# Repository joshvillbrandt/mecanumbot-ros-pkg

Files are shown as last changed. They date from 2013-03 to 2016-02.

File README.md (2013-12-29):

mecanumbot-ros-pkg
==================

A ROS package for the Mecanumbot robot.

## Summary

The Mecanumbot robot is a robotic development platform designed, built, and maintained by [Josh Villbrandt](mailto:josh@javconcepts.com). It features a holonomic drive platform with mecanum wheels as well as a 2D laser scanner and an RGB-D camera. Research goals in localization, navigation, and object recognition from point clouds. Learn more about the Mecanumbot at [JAV Concepts](http://javconcepts.com/tag/mecanumbot/).

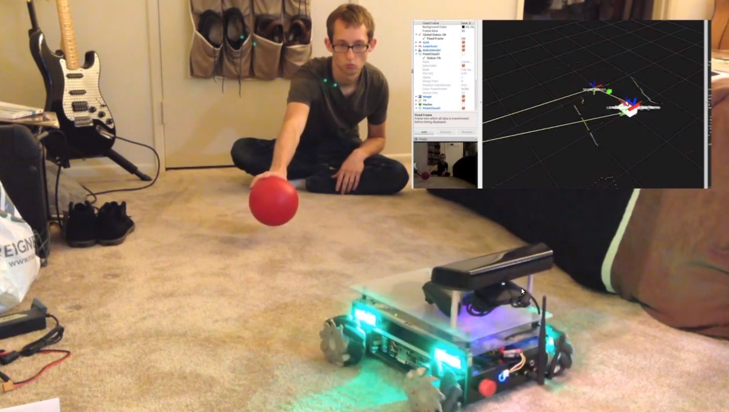
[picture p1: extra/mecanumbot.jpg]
Mecanumbot


## Documentation

A variety of guides are available in the `docs/` folder.

* [Setup Guide](docs/Setup Guide.md)
* [Usage Guide](docs/Usage Guide.md)
* [Implementation Guide](docs/Implementation Guide.md)
* [Work Log](docs/Work Log.md)
* [Todo List](docs/Todo List.md)

## Releases

This package uses [semantic versioning](http://semver.org/).

| Version | Notes |
| --- | --- |
| future | Re-added gmapping launch file. |
| future | Target follower now uses dynamic_reconfigure. Fixed phantom LED and motor message. |
| future | Refactoring LED messages and xbox controller mapping for LEDs. Added barometer telemetry. Refactored documentation.  |
| [v0.3.0](https://github.com/joshvillbrandt/mecanumbot/releases/tag/v0.3.0) | Ball tracking code refactored to HSV. Added power board telemetry. |
| [v0.2.0](https://github.com/joshvillbrandt/mecanumbot/releases/tag/v0.2.0) | Updating for Hydro. New ball tracking with target follower. |
| [v0.1.0](https://github.com/joshvillbrandt/mecanumbot/releases/tag/v0.1.0) | Last working version of the mecanumbot package for ROS Groovy. |

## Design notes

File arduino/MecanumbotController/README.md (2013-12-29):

mecanumbot-controller
=====================

An Arduino sketch for the mecanumbot low-level control node.

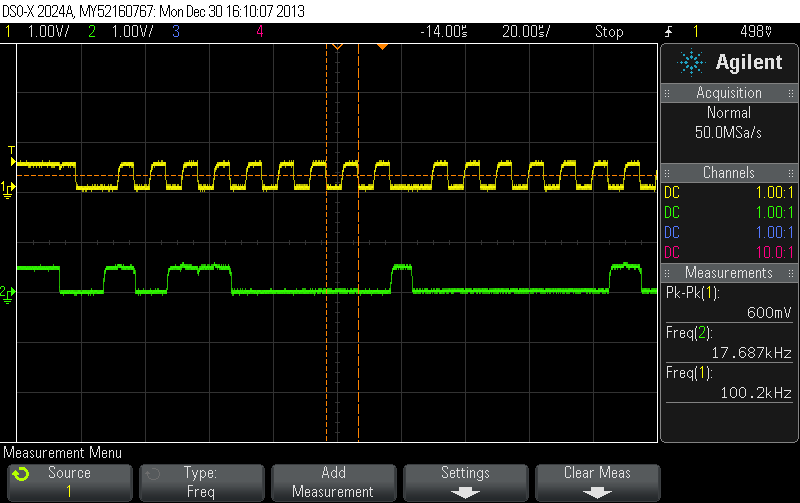
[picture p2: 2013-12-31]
extra/i2c_2.8k.png

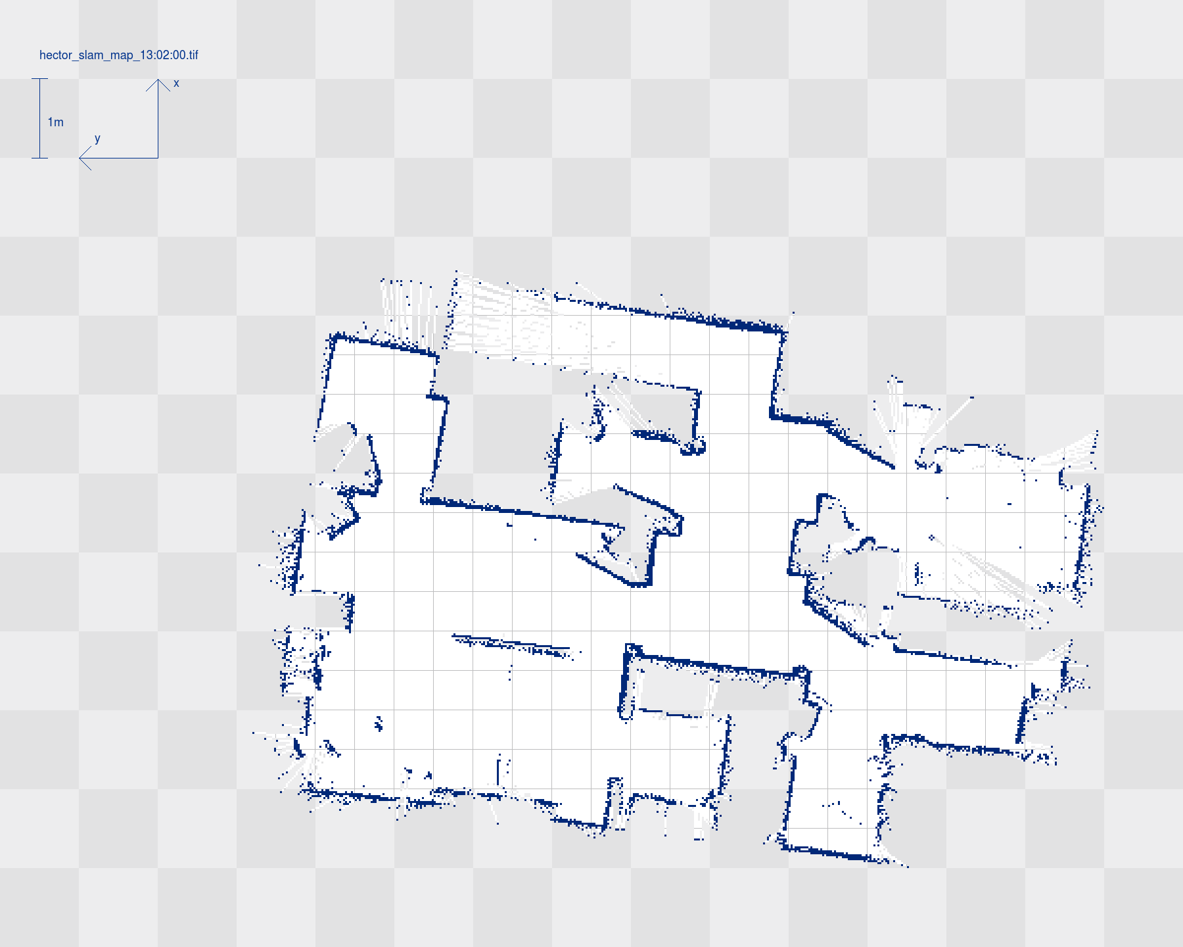
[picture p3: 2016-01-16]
maps/hector_slam_map_apartment_upstairs.tif

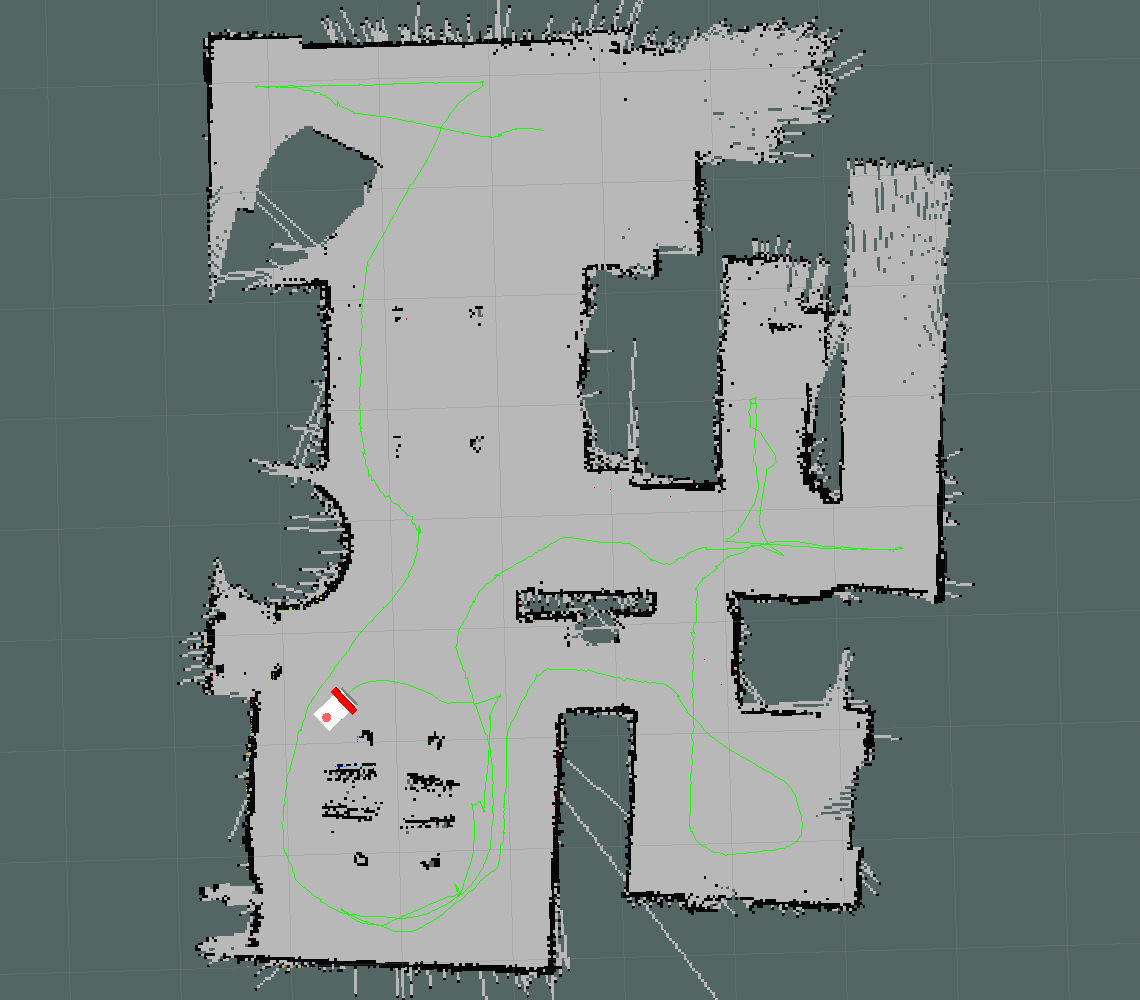
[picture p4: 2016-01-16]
maps/hector_slam_map_apartment_downstairs.jpg

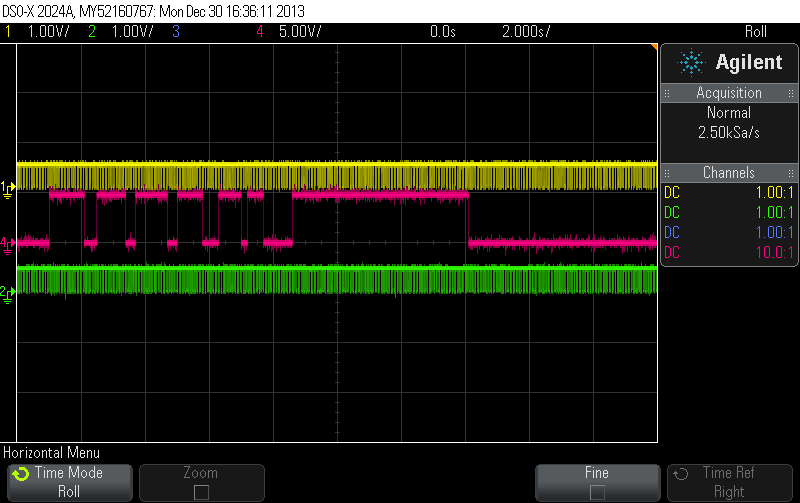
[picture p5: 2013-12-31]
extra/i2c_outpin.png

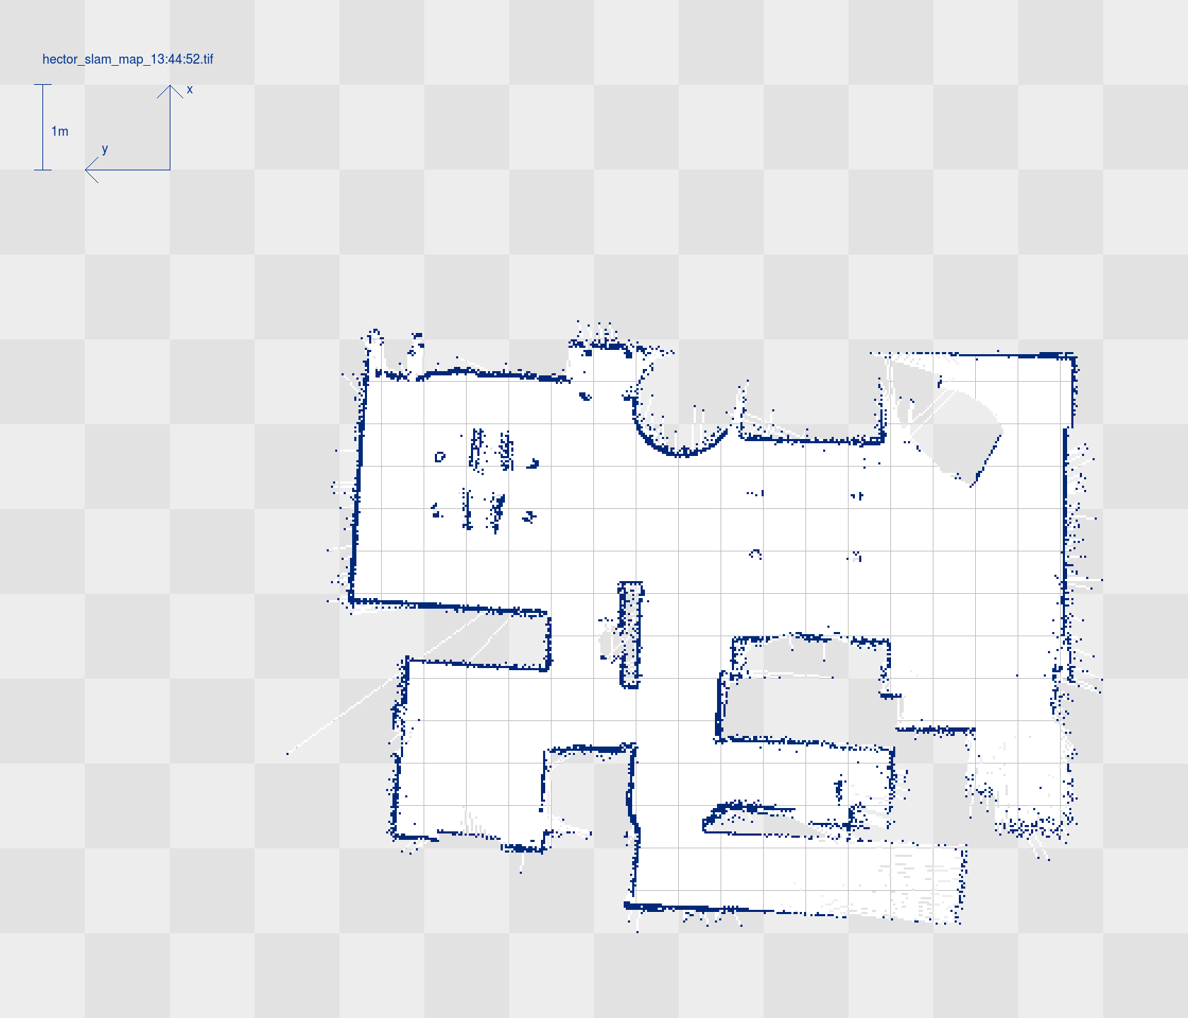
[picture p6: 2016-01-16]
maps/hector_slam_map_apartment_downstairs.tif

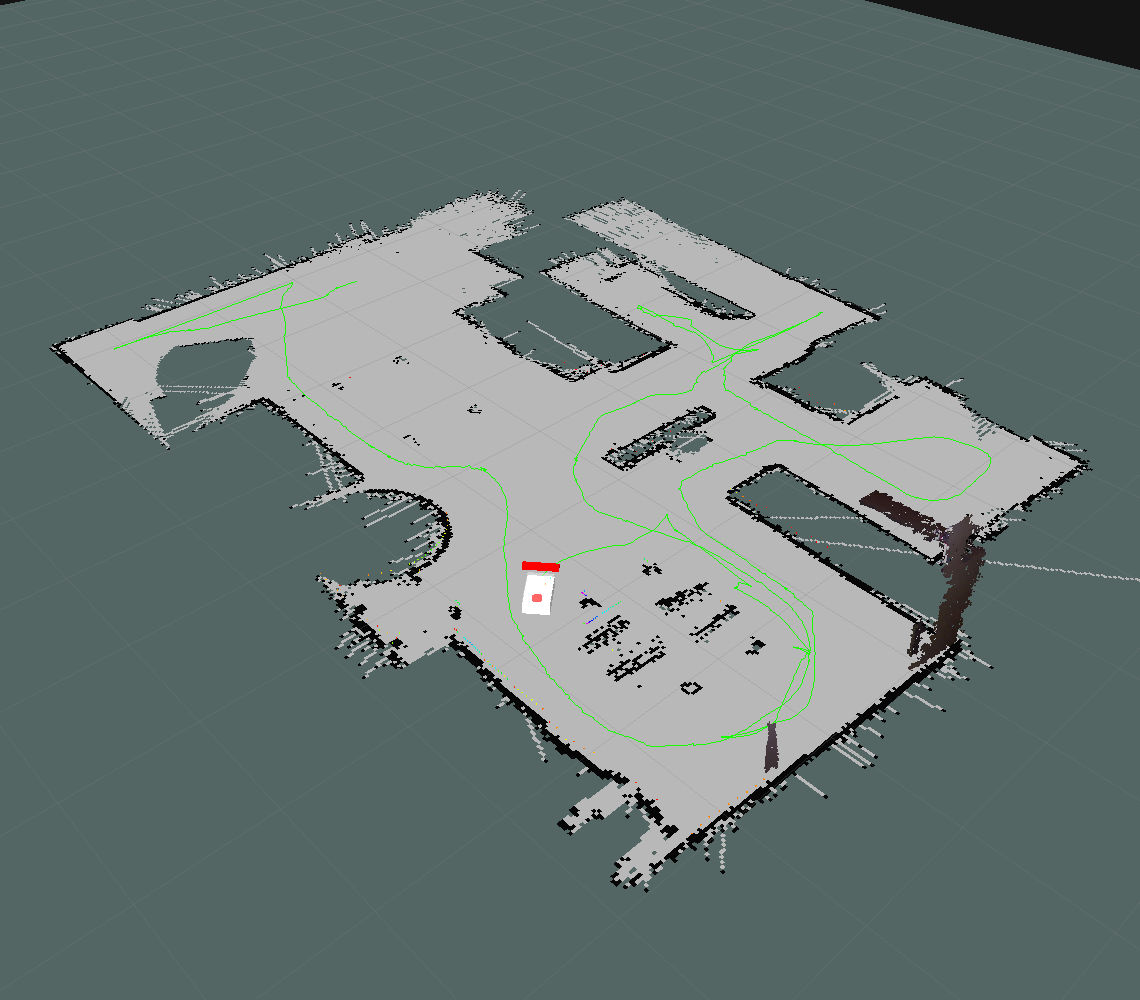
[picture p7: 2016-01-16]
maps/hector_slam_map_apartment_downstairs_iso.jpg

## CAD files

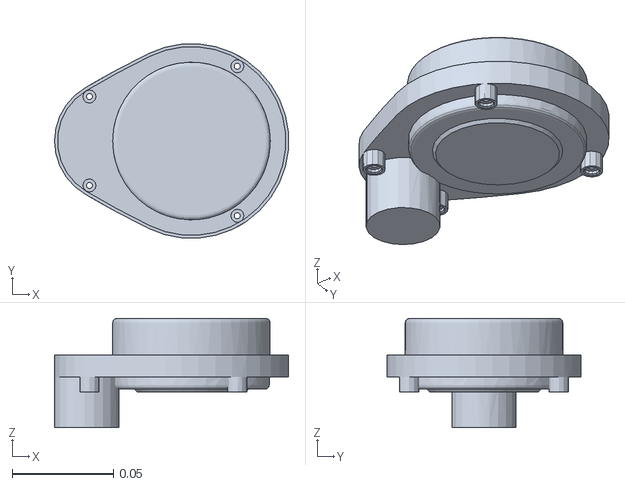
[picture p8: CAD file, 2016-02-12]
description/base_laser.STL
0.116 x 0.0961 x 0.054

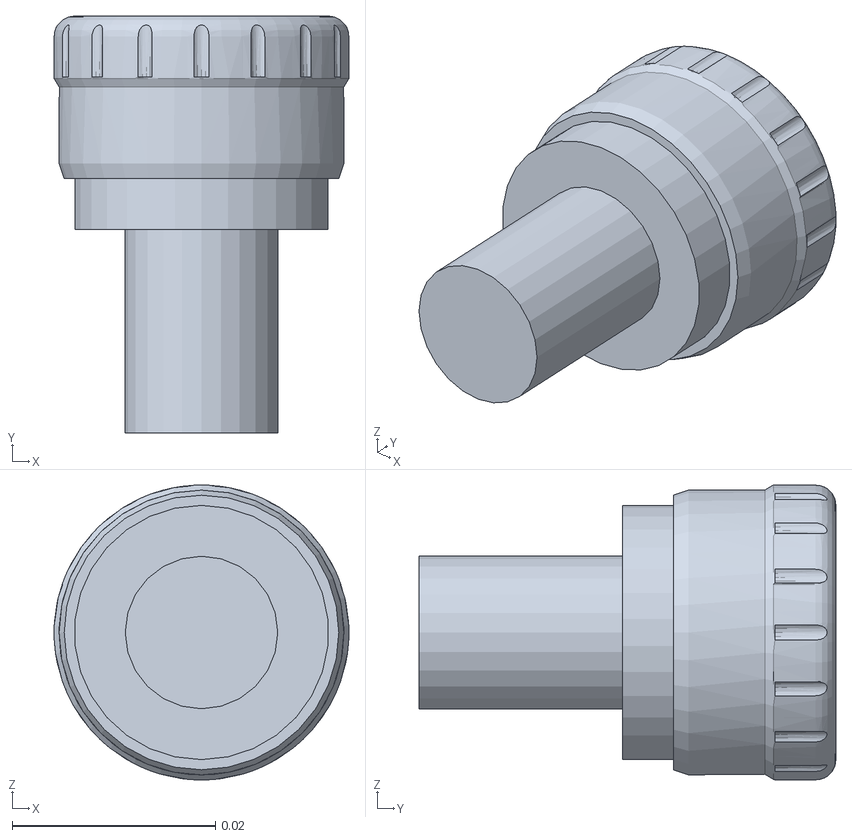
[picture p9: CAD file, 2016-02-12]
description/e_stop.STL
0.029 x 0.041 x 0.029

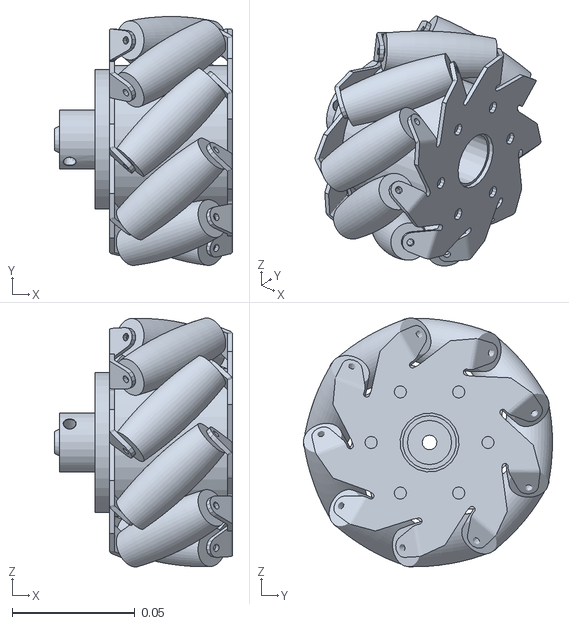
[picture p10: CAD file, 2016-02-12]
description/fr_wheel_link.STL
0.0724 x 0.101 x 0.101

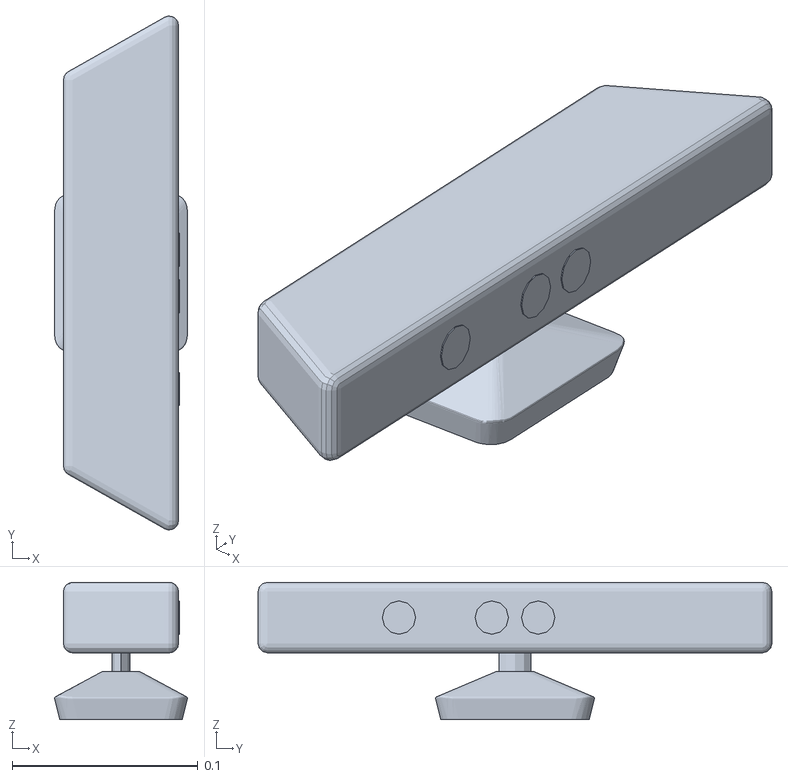
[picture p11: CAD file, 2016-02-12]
description/camera_link.STL
0.0716 x 0.277 x 0.074

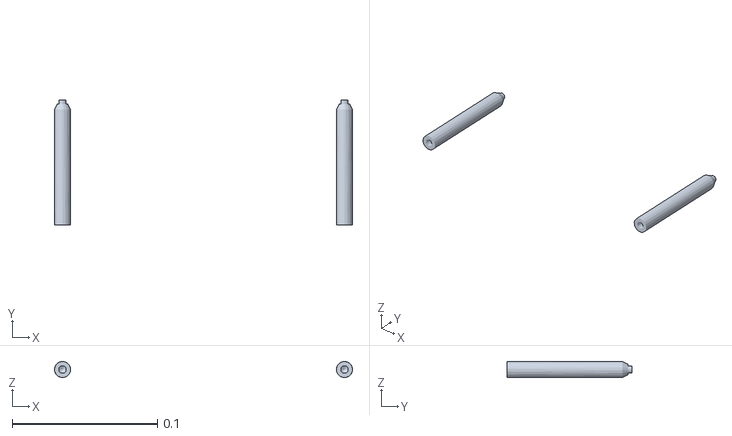
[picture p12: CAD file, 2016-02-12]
description/camera_supports.STL
0.205 x 0.0859 x 0.0111

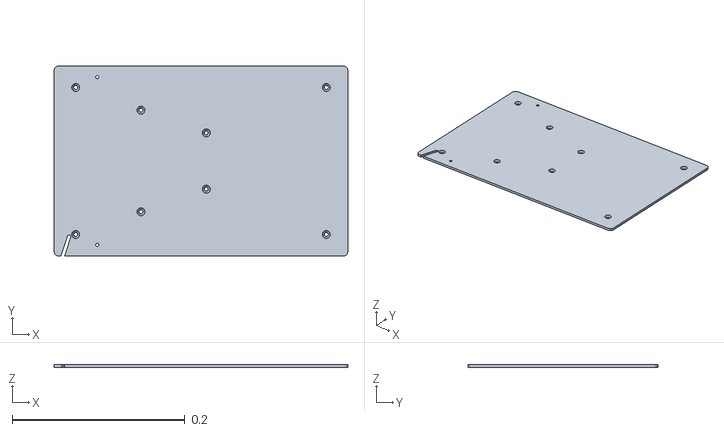
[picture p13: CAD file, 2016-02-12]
description/top_plate_link.STL
0.34 x 0.22 x 0.00317

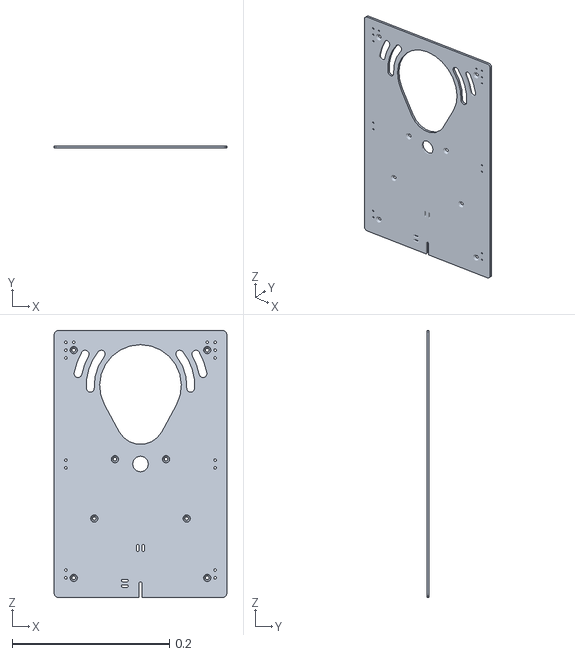
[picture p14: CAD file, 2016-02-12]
description/mid_plate_link.STL
0.22 x 0.00317 x 0.34

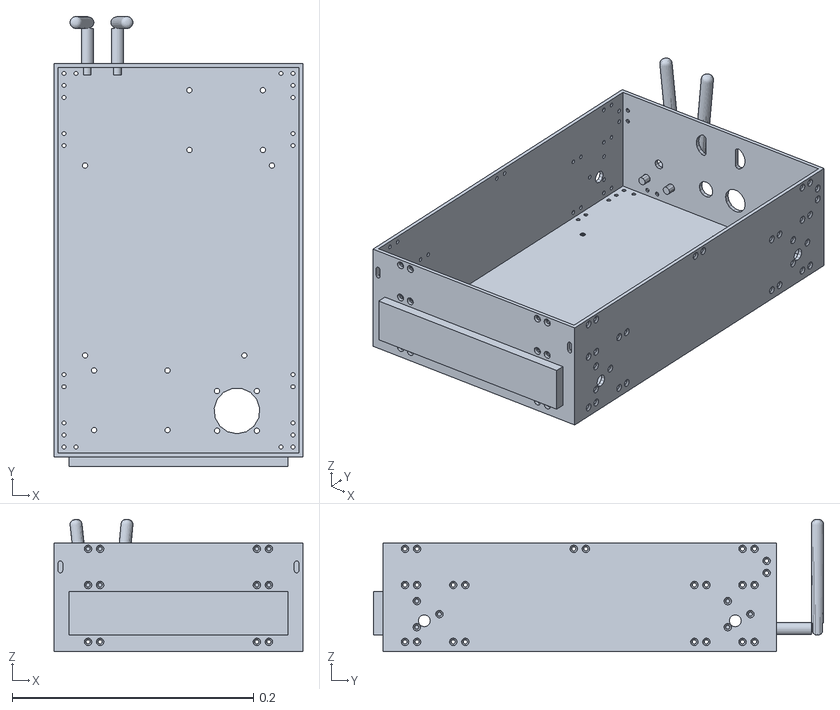
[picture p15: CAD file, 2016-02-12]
description/base_link.STL
0.206 x 0.373 x 0.11

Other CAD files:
description/bl_wheel_link.STL
description/br_wheel_link.STL
description/fl_wheel_link.STL

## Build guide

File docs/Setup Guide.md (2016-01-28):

# Mecanumbot Setup Guide

Complete the following steps to install the mecanumbot package on a new robot. If you are not familiar with ROS, please complete the [ROS Tutorials](http://wiki.ros.org/ROS/Tutorials) before continuing.

## Install Ubuntu 14.04

Use your favorite method to install a fresh copy of Ubuntu Trusty. Pay special attention to the hostname you choose during installation - this will be the hostname of your robot.

After installtion completes, install these additional, required packages:

```bash
sudo apt-get update
sudo apt-get install -y git openssh-server screen
```

## Optional Environment Setup

The following packages are optional and are intended for a development workstation:

```bash
# old gnome (don't forget to enable "Static Application Switcher" for alt-tab)
sudo apt-get install -y gnome-session-fallback compiz compiz-plugins-extra compizconfig-settings-manager

# sublime 3
sudo add-apt-repository ppa:webupd8team/sublime-text-3
sudo apt-get update
sudo apt-get install -y sublime-text-installer

# zsh
sudo apt-get install -y zsh
chsh -s $(which zsh)
sh -c "$(wget https://raw.github.com/robbyrussell/oh-my-zsh/master/tools/install.sh -O -)"

# scm_breeze
git clone git://github.com/ndbroadbent/scm_breeze.git ~/.scm_breeze
~/.scm_breeze/install.sh
source ~/.zshrc
```

## Install ROS

If you have earlier versions of ROS installed, it might be best to uninstall them first. If you have problems with the subsequent install statements, try using aptitude instead of apt-get to resolve dependencies.

```
sudo apt-get purge ros-indigo-*
```

Follow the [ROS Jade Install Guide](http://wiki.ros.org/jade/Installation/Ubuntu) to get ROS up an running. This boils down to:

```bash
sudo sh -c 'echo "deb http://packages.ros.org/ros/ubuntu $(lsb_release -sc) main" > /etc/apt/sources.list.d/ros-latest.list'
sudo apt-key adv --keyserver hkp://pool.sks-keyservers.net:80 --recv-key 0xB01FA116
sudo apt-get update
sudo apt-get install -y ros-jade-desktop-full
sudo rosdep init
rosdep update
```

In addition to the standard desktop package, you'll want to install a few other packages that the mecanumbot package depends on. The first few lines of this are from the [PCL Ubuntu install page](http://pointclouds.org/downloads/linux.html).

```bash
sudo add-apt-repository ppa:v-launchpad-jochen-sprickerhof-de/pcl
sudo apt-get update
sudo apt-get install -y libpcl-all ros-jade-pcl-ros ros-jade-joy ros-jade-openni-camera ros-jade-openni-launch ros-jade-rosserial-arduino ros-jade-rosserial ros-jade-robot-upstart ros-jade-rqt-robot-plugins ros-jade-hector-slam
```

To complete the install, source the ROS bash file. You'll probably want to stick this in your `~/.zshrc` file as well.

```bash
# for bash
echo "source /opt/ros/jade/setup.bash" >> ~/.bashrc
source ~/.bashrc

# for zsh
echo "source /opt/ros/jade/setup.zsh" >> ~/.zshrc
source ~/.zshrc
```

## Create a Workspace

Create a Catkin workspace by following the [create a workspace](http://wiki.ros.org/catkin/Tutorials/create_a_workspace) guide on ros.org. This boils down to:

```bash
mkdir -p ~/catkin_ws/src
cd ~/catkin_ws/src
catkin_init_workspace
cd ~/catkin_ws
catkin_make
```

Just like with the primary ROS install, you'll want to source the newly created bash setup file as well as adding it to your `~/.zshrc` file.

```bash
echo "source ~/catkin_ws/devel/setup.zsh" >> ~/.zshrc
source ~/.zshrc
```

## Clone the Mecanumbot Package

```bash
git clone https://github.com/joshvillbrandt/mecanumbot-ros-pkg.git ~/catkin_ws/src/mecanumbot
cd ~/catkin_ws
catkin_make
```

Set up unique identifiers for USB devices by linking to custom device rules and make sure users are a part of the dialup group

```bash
sudo cp ~/catkin_ws/src/mecanumbot/extra/99-usb-serial.rules /etc/udev/rules.d/

# to immediately reload the rules without restarting
sudo udevadm control --reload-rules && sudo service udev restart && sudo udevadm trigger
```

## Set up the Kinect

The instructions were copied from the TurtleBot documentation at http://learn.turtlebot.com/2015/02/01/5/.

```bash
mkdir ~/kinectdriver
cd ~/kinectdriver
git clone https://github.com/avin2/SensorKinect
cd SensorKinect/Bin/
tar xvjf SensorKinect093-Bin-Linux-x64-v5.1.2.1.tar.bz2
cd Sensor-Bin-Linux-x64-v5.1.2.1/
sudo ./install.sh
```

## Set up the XV-11 Laser

```bash
cd ~/catkin_ws/src
git clone https://github.com/rohbotics/xv_11_laser_driver.git
sudo adduser $(whoami) dialout
cd ~/catkin_ws
catkin_make
```

## Set up upstart

To automatically launch ROS on startup:

```bash
rosrun robot_upstart install mecanumbot/launch/core.launch
```

Manually control the upstart job with these:

```bash
sudo service mecanumbot start
sudo service mecanumbot stop
```

Check the log like this:

```bash
sudo tail /var/log/upstart/mecanumbot.log -n 30
```

## Extra

These setup steps aren't always necessary.

### New udev Rules

Check out [this syntax guide](http://www.reactivated.net/writing_udev_rules.html#syntax) for creating new udev rules. To identify properties of currently plugged in devices, try a command like this:

```bash
udevadm info -a -n /dev/ttyUSB0 | grep '{serial}' | head -n1
```

Rules are automatically ran at startup. To automatically reload the rules without restarting, run:

```bash
sudo udevadm control --reload-rules && sudo service udev restart && sudo udevadm trigger
```

### Installing Arduino Code

The following steps will allow you to update the onboard Arduino. Note that you must run `catkin_make` prior to this step in order to generate headers for custom message types.

```bash
mv ~/sketchbook ~/sketchbook_old
ln -s ~/catkin_ws/src/mecanumbot/arduino ~/sketchbook
cd ~/sketchbook/libraries
rm -rf ros_lib # just in case
rosrun rosserial_arduino make_libraries.py .
sudo apt-get install -y arduino arduino-core
```

Now open the [MecanumbotController](https://github.com/joshvillbrandt/MecanumbotController) sketch in the Arduino IDE, select board==Arduino Mega 2560 and the correct serial port (try `ls -l /dev | grep USB` and look for `arduino`) and click the upload button.

### Fix upower / Arduino Startup Bug

There seems to be a bug with the FTDI chip and the Ubuntu power saving component, upower. We can tell upower not to care about ttyUSB devices so that we can see the FTDI chip on startup. The following notes are taken from http://ten.homelinux.net/productivity/recipes/Arduino%20does%20not%20see%20ttyUSB0.

```bash
sudo vi /lib/udev/rules.d/95-upower-wup.rules
```

And look for an entry like:

> SUBSYSTEM=="tty", SUBSYSTEMS=="usb", ATTRS{idVendor}=="0403", ATTRS{idProduct}=="6001", ATTRS{serial}=="A80?????", ENV{UPOWER_VENDOR}="Watts Up, Inc.", ENV{UPOWER_PRODUCT}="Watts Up? Pro", ENV{UP_MONITOR_TYPE}="wup"

If present, comment the line (prepend the line by a "#") and then:

```bash
sudo /etc/init.d/udev restart

sudo killall upowerd

sudo lsof /dev/ttyUSB0
# should now report nothing
# Now, Arduino should give access to the USB interface.
```

More information [here](http://arduino.cc/forum/index.php?topic=104492.15 and http://bugs.debian.org/cgi-bin/bugreport.cgi?bug=586751).

### Pair the Wiimote

Run the following steps to start the wiimote node. The following steps are from http://www.ros.org/wiki/wiimote/Tutorials/StartingWiimoteNode.

```bash
sudo apt-get install -y python-rosdep
rosdep install wiimote
rosmake wiimote
rosrun wiimote wiimote_node.py
```

With a new Electric install, the libcwiid library will complain about an unknown symbol clock_gettime. The problem is with Electric's bundled version of the library. Run the following steps to install the stock library. From http://answers.ros.org/question/28084/problem-in-wiimote_nodepy/.

```bash
sudo apt-get install -y libcwiid1 libcwiid-dev
cd /opt/ros/electric/stacks/joystick_drivers/cwiid/cwiid/lib/
sudo mkdir old
sudo mv libcwiid.s* old
sudo ln -s /usr/lib/libcwiid.so libcwiid.so
sudo ln -s /usr/lib/libcwiid.so.1 libcwiid.so.1
sudo ln -s /usr/lib/libcwiid.so.1.0 libcwiid.so.1.0
```

I also installed everything on this page: https://help.ubuntu.com/community/CWiiD.

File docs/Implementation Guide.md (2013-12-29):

Mecanumbot Implementation Guide
===============================

This file discusses the implementation of various parts of the Mecanumbot package.

## High-Level Design Notes

### Control
The MecanumbotController Arduino sketch combines subscribes to the cmd_vel topic and translates and translates the message for the Mecanum library. The Mecanum library in turn send speed commands to each EMG30 motor on two Devantech MD25 motor contollers. The MecanumbotController also sends back odometry and responds to LED sequence commands.

## File-Specific Notes

### mecanumbot.urdf
The origin of the base_link frame for the mecanumbot is taken to be the center of the robot at the base of the ground. (This is 0.163m behind the front of the robot.) Following ROS Enhancement Proposal 103, x is forward, y is left, and z is up.

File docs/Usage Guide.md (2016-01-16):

# Mecanumbot Usage Guide

The core mecanumbot code is started with `roslaunch mecanumbot core.launch`. This will bring up the transform publisher, the laser scanner, and the rosserial client to the Arduino onboard the mecanumbot.

Launch rviz with the custom mecanumbot config with 'roslaunch mecanumbot rviz.launch'. To do this on a remote machine, be sure to run `export ROS_MASTER_URI=http://jvillbrandt-robot:11311` in your bash session first.

You can control the mecanumbot with a wireless Xbox remote by running `roslaunch mecanumbot teleop_xbox.launch`. To instead have the mecanumbot autonomously follow a red ball, run TODO and TODO instead.

## Using Screen

During the development, it is often easiest to manually launch the pertinent parts of the robot instead of starting everything on bootup. Using `screen` over SSH is the preferred manor of manual launching since it is robust against disconnects. To start the robot with this method, open a terminal on another computer (not the robot) and type the following:

```bash
ssh -Y jvillbrandt-robot.local
screen
roslaunch mecanumbot core.launch
# [ctrl-a] [c]
# other stuff here like roslaunch mecanumbot teleop_xbox.launch
# [ctrl-a] [n] # go to the next window
```

If you drop the connection to the robot, reconnect with this:

```bash
screen -ls
screen -r DESIRED_SCREEN_ID
```

To learn more about screen, check out [this tutorial](http://www.rackaid.com/resources/linux-screen-tutorial-and-how-to/).

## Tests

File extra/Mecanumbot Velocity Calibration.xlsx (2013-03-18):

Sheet: front back
t (s) | x (m) | dx/dt (m/s)
0.4 | 0
0.4666666667 | 0.0173122427 | 0.2596836405
0.5 | 0.030072365 | 0.382803669
0.5666666667 | 0.04177328596 | 0.1755138144
0.6 | 0.07318103456 | 0.9422324581
0.6333333333 | 0.09945677447 | 0.7882721973
0.6666666667 | 0.1337384211 | 1.028449398
0.7333333333 | 0.1651461697 | 0.4711162291
0.7666666667 | 0.1965539001 | 0.9422319131
0.8 | 0.2308355467 | 1.028449398
0.8333333333 | 0.2716861328 | 1.225517583
0.9 | 0.31253672 | 0.6127588086
0.9333333333 | 0.3519503265 | 1.182408194
0.9666666667 | 0.3899269987 | 1.139300167
1 | 0.4242086453 | 1.028449398
1.066666667 | 0.4593114082 | 0.5265414433
1.1 | 0.4921560967 | 0.9853406553
1.133333333 | 0.5330066919 | 1.225517856
1.166666667 | 0.5621563479 | 0.8744896817
1.233333333 | 0.5972591108 | 0.5265414434
1.266666667 | 0.6278457431 | 0.917598969
1.3 | 0.6672593802 | 1.182409113
1.333333333 | 0.7052360593 | 1.139300371
1.4 | 0.7352068316 | 0.4495615854
1.433333333 | 0.7694884601 | 1.028448853
1.466666667 | 0.8089021153 | 1.182409658
1.5 | 0.8417468039 | 0.9853406553
1.566666667 | 0.8825973627 | 0.6127583828
1.6 | 0.9205740417 | 1.139300371
1.633333333 | 0.9519817904 | 0.9422324581
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

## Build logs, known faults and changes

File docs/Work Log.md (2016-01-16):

Mecanumbot Work Log
===================

Entries listed from newest to oldest.

## 15 January 2016, Josh Villbrandt

* created a "hazards enable" service on the arduino to enable and disable motor power
* the mecanumbot boots up with hazards disabled and red flashing LEDs
* when hazards are enabled, green LEDs flash
* four headlight LEDs automatically turn on when a connection to the ROS master is made
* the two front, middle LEDs turn blue when wall power is being used
* updated the teleop_xbox node to call the hazards enable service when the A and B buttons are pressed
* an occasional timing delay in the LED flashes can be noted; this is because the timing is being controlled via the main loop of the arduino
* noted that the laser data sometimes appears to drop every other point (observed in rviz); todo: see if the length of the scan message changes
* fixed the Kinect and updated setup instructions for it
* it has been noted that the phantom wheel spins only start happening after a connection is established between the arduino and ROS

## 14 January 2016, Josh Villbrandt

* initial expirements with hector slam with and without the encoder odometry
* the odometry is not turned for turning on carpet, so the map looks a bit messed up
* when trying hector slam without odometry, the map -> base_link transform is not being published for some reason

## 13 January 2016, Josh Villbrandt

* upgraded the mecanumbot to use ROS Jade
* discovered that my Neato XV-11 Lidar is more stable when the spin motor is powered with a higher voltage; now using 4V instead of 3V
* hacked in a 15 Ohm resistor off of a 5V line to provide the 4V

## 1 January 2014, Josh Villbrandt

* phatom wheel spins still happening
 * noted that phantom wheel spins always seem to be full speed
 * having a faster cmd_vel publish rate mitigates the affect, because the full-speed command is quickly overwritten by the legitimate command
 * this maybe be related to why the wheels spin on power up some time.
* still also have phantom LED flashes, although way less frequently
 * this doesn't have anything to do with I2C, but is commanded by the same Arduino that sends the motor commands
 * maybe a memory problem on the Arduino? But this doesn't seem like it is the case...

## 29 December 2013, Josh Villbrandt

* added barometer telemetry in robot_health
* refactored documentation
* evaluated I2C bus pull up resistors
 * http://www.dsscircuits.com/articles/effects-of-varying-i2c-pull-up-resistors.html
 * R_pull_up_min = (Vcc - 0.4V)/3mA
  * this is a 1.5k resistor for 5V logic
 * R_pull_up_max = 1us / C_b (C_b = bus capacitance)
  * C_arduino is 10pF from the datasheet, so I'm assuming C_b is 50 pF since I also have four slaves
  * this equates to a 20k max pull up resistor
* also a good read: http://www.robot-electronics.co.uk/acatalog/I2C_Tutorial.html
* the Mecanumbot currently uses a 10k resistor each on the clock and data lines
* hooked up an oscope to the i2c bus and saw:
 * 100 kHz on average - spot on
 * 640mV peal to peak - this should be 5V
 * squareness of signal was pretty round for most of cycle - bad but not terrible
  * this matches the 10k resistor in the dsscircuits testing
  * would like to try 2.2k resistors instead
 * i2c bus falls flat when motor e-stop is enable meaning there is no comm even for to the barometer and the power board
  * i already knew this and can live with this...
 * slight dip in the clock line during the start signal... maybe the phantom wheel spins are coming from this dipping
 * changed resistance to 1.8k, 2.2k, and 2.8k and that had no affect (still wheel movements)
* other I2C experiments
 * removed power board and barometer from the bus - no affect (wheels still have occasional momentary jerk)
 * removing either SDA of SCL line from the primary microcontroller (the i2c master) stops all ghost wheel movements (but obviously stops all legitimate comm too)
  * tried hooking primary uC up via different wires to the other MD25 - no affect
  * maybe slave address colisions? 58, 59, 42, and 119
  * maybe try a different arduino? (need another arduino mega...)
  * maybe an interupt problem? maybe ROS vs I2C library?

## 28 December 2013, Josh Villbrandt

* finally routed board power telemetry through the primary arduino and then to ROS

## 24 December 2013, Josh Villbrandt

* ball tracker now uses HSV space for color filtering

## 15 December 2013, Josh Villbrandt

* created a tf average frame

## 8 December 2013, Josh Villbrandt

* migrated ball tracker to hydro

## 30 November 2013, Josh Villbrandt

* migrating repository to hydro
* teleop_xbox works in hydro

## 18 March 2013, Josh Villbrandt

* starting move to ROS Groovy / catkin build system
* starting move to github over svn.javconcepts.com for ROS and Arduino code
* files verified in catkin and Groovy:
 * extra/mecanumbot.rviz
 * extra/mecanumbot.urdf
 * launch/core.launch
 * launch/rviz.launch
 * src/odometry_publisher.cpp

## 12 December 2012, Josh Villbrandt

* updated xv_11_laser_driver with the following time_increment change:

    //scan->time_increment = motor_speed/good_sets/1e8;
    scan->time_increment = 10.6667 / (motor_speed / good_sets); //average time increment
    // JAV corrected this based on https://github.com/Xevel/NXV11/wiki
    // motor speed comes to use in 64*rpm
    // time_increment = 1 / (avg_motor_speed / 64 / 60) / 360

Still seeing a bit of wiggle when rotating the robot. This seems to indicate some lag in the odometry transform.

## 18 November 2012, Josh Villbrandt

* trying out hector slam

    cd ~/ros
    svn co http://tu-darmstadt-ros-pkg.googlecode.com/svn/branches/electric/hector_common/
    rosmake hector_common --rosdep-install
    svn co http://tu-darmstadt-ros-pkg.googlecode.com/svn/branches/electric/hector_slam/
    rosmake hector_slam --rosdep-install

## 17 November 2012, Josh Villbrandt

* updated to the more official laser driver which seems to have a lot less lag
 * still lags a bit rotationally, but not traslationally
* install the laser scan matcher to try and get odom that way

    cd ~/ros
    git clone git://github.com/ccny-ros-pkg/scan_tools.git
    rosmake scan_tools --rosdep-install
    roslaunch laser_scan_matcher demo.launch

## 3 November 2012, Josh Villbrandt

* found some websites that could help with the I2C blocking the rest of the MecanumController Arduino program
 * wire lib with timeout - http://dsscircuits.com/articles/arduino-i2c-master-library.html
 * another wire lib with timeout - https://groups.google.com/forum/?fromgroups=#!topic/ukhas/2n10YIKzudI https://github.com/whitestarballoon/Com-Controller/tree/SessionInitiationFixing/Libraries/WSWire
 * a way to scan the bus to see if the slave is present - http://todbot.com/blog/2009/11/29/i2cscanner-pde-arduino-as-i2c-bus-scanner/
* converted MD25 code to use the I2C library with timeout
* added a cmd_vel watchdog to MecanumController to zero the motors when no message has been received in a while

## 31 October 2012, Josh Villbrandt

* Velocity Calibration was preformed. Video of the Mecanumbot moving was taken with an iPhone 5 and analyzed with Avidemux.

| movement | t1 | t2 | dt | d/dt | units | d/dt | units |
| --- | --- | --- | --- | --- | --- | --- | --- |
| turning 1 rotation | 1.900 | 4.100 | 2.200 | 2.856 | rad/s |  |  |
| forward 4 ft | 1.233 | 2.633 | 1.400 | 0.350 | ft/s | 1.148 | m/s |
| sideways 4 ft | 1.666 | 3.266 | 1.600 | 0.400 | ft/s | 1.312 | m/s |

## 30 October 2012, Josh Villbrandt

* created launch file for gmapping, testing running gmapping - everything works!!
* tested out running nodes on a remote machine with a shared roscore master

## 29 October 2012, Josh Villbrandt

* finally understand the conflict between running odom publisher and cmd_vel subscriber at the same time on the Arduino - memory
* rosserial odom example already consumes all but ~100 bytes of RAM
* using custom "encoders" message (4 floats) and a node on the PC to convert to proper odom messages
* updated urdf origin to be at the center of the robot instead of the front because turning in place was showing up as turning about the front
* I finally have everything I need to run the nav stack! Woohoo!!!!!!!!

## 27 October 2012, Josh Villbrandt

* resolved the Arduino startup (upower) conflict

## 26 October 2012, Josh Villbrandt

* checked out most of the power board and wrote the MecanumPower Arduino program

## 23 October 2012, Josh Villbrandt

* MecanumController finally runs the motors from the Wiimote! Hurray!!!!
* TODO: move convertToMotor into the Mecanum Arduino library
* note that I still can't run odometry concurrently with the cmd_vel subscriber; not sure why
* updated teleop_wiimote LEDs

## 20 October 2012, Josh Villbrandt

* filled out teleop_wiimote
* add teleop.launch to start the wiimote node and the teleop_wiimote node
memory

## 16 October 2012, Josh Villbrandt

* added the laser driver to the repo - this is a copy (with removal of one program) of https://github.com/JBot/smart-robotics-ros-pkg/tree/master/neato_xv11_lds
* fixed the URDF to rotate the laser a tad
* verified the /dev/laser custom USB rule
* updated the start.launch file to properly start the laser
* updated the rviz config file to include the laser scan
* will probably decrease the "not seen" value in the laser driver - the value of 2600 is just weird
 * however, this value might tell mean to SLAM that there is in fact empty space from 0 to "not seen" value which is reasonable assumption up until this range

## 13 October 2012, Josh Villbrandt

* The thinkpenguin.com bluetooth dongle was dead on arrival, however the customer support was very good and the agreed to send me out another one on Monday. Hopefully that one will work...
* Got two of my Neato Laser USB bored populated. They work with one fix - the laser logic needs 3.3V and not 3.0V, so a jumper to the 3.3 line needs to be attached.
* Instructions from http://www.ros.org/wiki/xv_11_laser_driver/Tutorials/Running%20the%20XV-11%20Node don't seem to work for laser firmware V2.6.
* Forum thread http://forums.trossenrobotics.com/showthread.php?4936 and code from https://github.com/JBot/smart-robotics-ros-pkg/tree/master/neato_xv11_lds worked however.
* Laser data in ROS with my board, woohoo!
* Next up is a piggy-back node that removes the four screws in the field of view.

## 5 October 2012, Josh Villbrandt

* created the teleop_wiimote node
* the bluetooth adapter i had from an old Microsoft mouse didn't work in Ubuntu, ordered a new dongle from thinkpenguin.com
* ROS / Arduino serial communication is continueing to give me lots of problems.

## 22 September 2012, Josh Villbrandt

* found problem between ROS and RC Arduino code.. using pulseIn() takes about 30% CPU for each channel reading in (as noted here: http://diydrones.com/profiles/blog/show?id=705844:BlogPost:38418)
* trying a lower timeout of 20000 (dsudo lsof /dev/ttyUSB0efault is 1000000us)
* will probably have to move to an interupt/timer based RC library like http://arduino.cc/playground/Code/ReadReceiver
* need to look at aeroquad or ardupilot for ready-made RC library
* I might simply not support RC driving from now on - long term goal is just to have a remote running through ROS anyway
 * benefit is that is less code stored on the Arduino
 * downside is that I can manually drive the robot without the computer being on

## 26 August 2012, Josh Villbrandt

* updated to new readme.html format
* started MecanumController arduino sketch
 * outputting fake odometry
 * successfully listening to the cmd_vel topic

## 25 August 2012, Josh Villbrandt

* created ball_tracker node to follow a red ball
* created a udev rule for the Mecanumbot Arduino
* added the rosserial_python command to start.launch

## 17 August 2012, Josh Villbrandt

* set up mecanumbot.urdf and start.launch

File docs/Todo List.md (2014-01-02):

Mecanumbot Todo List
====================

## Mecanumbot Core

* BUG: occasional loss of comm (~once every 5 minutes) with MecanumbotController arduino 
 * sometimes does not recover when sending lots of commands via the remote
 * sometimes does not connect at all!
 * monitor arduino cpu and mem with rqt plot
* BUG: occasional "hick-ups" in motor controller - wheels spin for a moment without command
 * suspect this is bad resistors on the I2C bus, check with oscope
* BUG: laser data goes totally wack every few seconds... this is something with the new hydro driver
* BUG: xbox controller udev rule doesn't always work
* FEATURE: move installation dependencies to the package.xml file and provide a method to auto-install
* FEATURE: start ros on system startup

## Robot LEDs
* BUG: occasional random `light_control` messages, or so it seems anyway
* FEATURE: change `light_control` to an action instead of a continuous message
* FEATURE: add support for the top plate LEDs in `light_control`
* change message/action format:
 * unit8 strand (0=all, 1=headlights, 2=internal, 3=sides, 4=topdeck)
 * unit8 pattern (0=off, 1=on, 2=flashing on/off, 3=quick double flash, 4= in to out/front to back/cylon, 5 = ou to in/back to front)
 * unit8 color (0=white, 1=red, 2=orange, 3=yellow, 4=green, 5=cyan, 6=blue, 7=purple, 8=magenta, 9=rainbow)
 * unit8 brightness (0=0%, 255=100%)

## Teleop Xbox Controller

* set up `teleop_xbox` as a safety controller - only publish `cmd_vel` from xbox controller when xbox controller is enable
* include some motion kill switch
* toggle target following
* new key bindings:
 * D-pad up/down - toggle headlight brightness
 * D-pad left/right - toggle other light modes
 * B (red) - emergency stop; disable motors and flash lights red
 * A (green) - enable motors
 * X (blue) - enable controller cmd_vel output
 * Y (yellow) - enable target following

## Ball Tracker

* FEATURE: try using a Kalman filter to better track a ball
* FEATURE: throttle point cloud (http://wiki.ros.org/topic_tools/throttle)
* FEATURE: calibrate Kinect using [this guide](http://wiki.ros.org/openni_launch/Tutorials/IntrinsicCalibration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)
* FEATURE: register and identify targets between frames
* FEATURE: experiment with [difference of normals segmentation](http://pointclouds.org/documentation/tutorials/don_segmentation.php)
* learn from [turtlebot-follower](https://github.com/turtlebot/turtlebot_apps/blob/hydro/turtlebot_follower/src/follower.cpp) app:
 * use nodelet to avoid pointcloud serialization
 * use service to start and stop follow
 * dynamic reconfigure looks pretty easy here!

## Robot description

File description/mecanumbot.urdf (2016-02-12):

<robot name="mecanumbot">
  <link name="base_link">
    <inertial>
      <origin xyz="-0.0468302529926084 -0.0134185737759999 -0.0824261310140349" rpy="0 0 0" />
      <mass value="0.963214943605585" />
      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
    </inertial>
    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
  </link>
  <link name="fl_wheel_link">
    <inertial>
      <origin xyz="0.02108 -8.5029E-07 3.7806E-05" rpy="0 0 0" />
      <mass value="0.33461" />
      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
    </inertial>
    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
  </link>
  <joint name="base_link_to_fl_wheel_joint" type="continuous">
    <origin xyz="0.0788531486544269 -0.147251192141458 -0.0851412158001636" rpy="1.5707963267949 0 0" />
    <parent link="base_link" />
    <child link="fl_wheel_link" />
    <axis xyz="-1 0 0" />
  </joint>
  <link name="fr_wheel_link">
    <inertial>
      <origin xyz="0.021164 5.4602E-06 -1.1653E-05" rpy="0 0 0" />
      <mass value="0.33461" />
      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
    </inertial>
    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
  </link>
  <joint name="base_link_to_fr_wheel_joint" type="continuous">
    <origin xyz="-0.168291019374608 -0.147251192141458 -0.0851412158001628" rpy="2.08567039686228 0 3.14159265358979" />
    <parent link="base_link" />
    <child link="fr_wheel_link" />
    <axis xyz="1 0 0" />
  </joint>
  <link name="bl_wheel_link">
    <inertial>
      <origin xyz="0.021164 7.7945E-06 -6.7187E-06" rpy="0 0 0" />
      <mass value="0.33461" />
      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
    </inertial>
    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
  </link>
  <joint name="base_link_to_bl_wheel_joint" type="continuous">
    <origin xyz="0.0788180033333974 0.110748807858542 -0.0851412158001625" rpy="1.5707963267949 0 0" />
    <parent link="base_link" />
    <child link="bl_wheel_link" />
    <axis xyz="1 0 0" />
  </joint>
  <link name="br_wheel_link">
    <inertial>
      <origin xyz="0.02108 -3.0956E-06 3.2979E-05" rpy="0 0 0" />
      <mass value="0.33461" />
      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
    </inertial>
    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
  </link>
  <joint name="base_link_to_br_wheel_joint" type="continuous">
    <origin xyz="-0.168326164695638 0.110748807858543 -0.0851412158001639" rpy="2.07266866801634 0 3.14159265358979" />
    <parent link="base_link" />
    <child link="br_wheel_link" />
    <axis xyz="-1 0 0" />
  </joint>
  <link name="base_laser">
    <inertial>
      <origin xyz="-0.00610408561341411 4.74394690197499E-10 -0.0117846353165668" rpy="0 0 0" />
      <mass value="0.209244181201808" />
      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
    </inertial>
    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
  </link>
  <joint name="base_link_to_base_laser" type="fixed">
    <origin xyz="-0.0447365080206049 -0.117567277135445 -0.00506621580016293" rpy="0 -6.12303176911189E-17 -1.5707963267949" />
    <parent link="base_link" />
    <child link="base_laser" />
    <axis xyz="0 0 0" />
  </joint>
  <link name="mid_plate_link">
    <inertial>
      <origin xyz="1.6128E-05 0.0015881 -0.017739" rpy="0 0 0" />
      <mass value="0.23689" />
      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
    </inertial>
    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
  </link>
  <joint name="base_link_to_mid_plate_link" type="fixed">
    <origin xyz="-0.0447365080206053 -0.0182511921414576 -0.0204662158001629" rpy="1.5707963267949 0 0" />
    <parent link="base_link" />
    <child link="mid_plate_link" />
    <axis xyz="0 0 0" />
  </joint>
  <link name="top_plate_supports">
    <inertial>
      <origin xyz="0.032556 -0.021976 6.3957E-07" rpy="0 0 0" />
      <mass value="0.011427" />
      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
    </inertial>
    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
  </link>
  <joint name="mid_plate_link_to_top_plate_supports" type="fixed">
    <origin xyz="-0.0325563676649805 0.015675 0.006161057906821" rpy="1.5707963267949 0 0" />
    <parent link="mid_plate_link" />
    <child link="top_plate_supports" />
    <axis xyz="0 0 0" />
  </joint>
  <link name="top_plate_link">
    <inertial>
      <origin xyz="-0.16966 0.00013265 -0.0015888" rpy="0 0 0" />
      <mass value="0.28331" />
      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
    </inertial>
    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
  </link>
  <joint name="top_plate_supports_to_top_plate_link" type="fixed">
    <origin xyz="0.0325563676649805 0.163838942093179 -0.015675" rpy="3.14159265358979 -8.67361737988403E-17 1.5707963267949" />
    <parent link="top_plate_supports" />
    <child link="top_plate_link" />
    <axis xyz="0 0 0" />
  </joint>
  <link name="camera_supports">
    <inertial>
      <origin xyz="0.097 0.042365 2.7756E-17" rpy="0 0 0" />
      <mass value="0.041975" />
      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
    </inertial>
    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
  </link>
  <joint name="top_plate_link_to_camera_supports" type="fixed">
    <origin xyz="-0.29 -0.097 0" rpy="1.5707963267949 0 1.5707963267949" />
    <parent link="top_plate_link" />
    <child link="camera_supports" />
    <axis xyz="0 0 0" />
  </joint>
  <link name="camera_link">
    <inertial>
      <origin xyz="-0.029956 9.3245E-05 -0.0070276" rpy="0 0 0" />
      <mass value="0.69591" />
      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
    </inertial>
    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
  </link>
  <joint name="camera_supports_to_camera_link" type="fixed">
    <origin xyz="0.097 0.10242 0.0175000000000002" rpy="-1.5707963267949 -1.5707963267949 0" />
    <parent link="camera_supports" />
    <child link="camera_link" />
    <axis xyz="0 0 0" />
  </joint>
  <link name="e_stop">
    <inertial>
      <origin xyz="3.4694E-18 0.0063686 0" rpy="0 0 0" />
      <mass value="0.016321" />
      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
    </inertial>
    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
  </link>
  <joint name="base_link_to_e_stop" type="fixed">
    <origin xyz="0.0184384919793947 0.144923807858542 -0.0836412158001629" rpy="-6.12303176911189E-17 0 0" />
    <parent link="base_link" />
    <child link="e_stop" />
    <axis xyz="0 0 0" />
  </joint>
</robot>

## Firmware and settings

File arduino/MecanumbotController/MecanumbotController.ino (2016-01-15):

/*
  MecanumbotController.ino - Mecanumbot low-level ROS driver.
  Created by Josh Villbrandt (http://javconcepts.com/), July 19, 2012.
  Released into the public domain.
*/

#include "Arduino.h"

// Health
#include <I2C.h>
#include <I2c_BMP085.h>
#include <Utils.h>
const byte PWR_ADDRESS = 42;
#define PRESSURE_SL 101600 // Pa (=1016mb http://w1.weather.gov/obhistory/KLAX.html)

// Mecanum
#include <MD25.h>
#include <Mecanum.h>
#define COUNTS_TO_METERS (0.6283185 / 360.0)

// ROS
#include <ros.h>
#include <ros/node_handle.h>
#include <geometry_msgs/Twist.h>
#include <std_msgs/Float32MultiArray.h>
#include <std_msgs/UInt32.h>
#include <mecanumbot/RobotHazardsEnable.h>
#include <mecanumbot/RobotHealth.h>

// LEDs
#include "LPD8806.h"
#include "SPI.h"
#define NUM_LEDS 16
#define LED_DATA_PIN 8
#define LED_CLOCK_PIN 9
#define COLOR_WHITE  strip.Color(127, 127, 127)
#define COLOR_RED    strip.Color(127,   0,   0)
#define COLOR_YELLOW strip.Color(127,  95,   0) // color correction
#define COLOR_GREEN  strip.Color(  0, 127,   0)
#define COLOR_CYAN   strip.Color(  0, 127, 127)
#define COLOR_BLUE   strip.Color(  0,   0, 127)
#define COLOR_VIOLET strip.Color(127,   0, 127)
#define COLOR_OFF    0

// Loop Periods
#define ODOM_PERIOD 50 // 20 Hz
#define WATCHDOG_PERIOD 500 // 2 Hz
#define HEALTH_PERIOD 1000 // 1 Hz

// Global Variables
Utils utils;
Mecanum controller;
ros::NodeHandle  nh;
std_msgs::Float32MultiArray enc_msg;
ros::Publisher enc_pub("encoders", &enc_msg);
mecanumbot::RobotHealth health_msg;
ros::Publisher health_pub("robot_health", &health_msg);
unsigned long health_timer = 0;
unsigned long odom_timer = 0;
unsigned long watchdog_timer = 0;
boolean hazards_enabled = false;
byte lights = 4; // bitmask LSB:[internal, front, hazards, top in, top out, blank, blank, blank]
LPD8806 strip = LPD8806(NUM_LEDS, LED_DATA_PIN, LED_CLOCK_PIN);
I2c_BMP085 bmp;

// convert to motor
// TODO: move this into the Mecanum library
#define LINEAR_X_MAX_VEL 1.1 // m/s
#define LINEAR_Y_MAX_VEL 1.3 // m/s
#define ANGULAR_Z_MAX_VEL 2.8 // rad/s
#define DEADZONE 5 // in bytes around 128
byte convertToMotor(float value, float maxValue) {
  value = constrain(value, -1.0 * maxValue, maxValue);
  byte r = map(value*256.0, -1.0 * maxValue * 256.0, maxValue * 256.0, 0.0, 256.0);
  if(value >= maxValue) r = 255; // i guess i don't understand how map works
  
  // enforce deadzone around 128
  if(r >= 128-DEADZONE && r <= 128+DEADZONE) r = 128;
  
  return r;
}

// Mecanum cmd_vel Callback    
void vel_callback(const geometry_msgs::Twist& cmdvel) {
  if(hazards_enabled) {
    controller.cmd_vel(
      convertToMotor(cmdvel.linear.x, LINEAR_X_MAX_VEL),
      convertToMotor(cmdvel.linear.y, LINEAR_Y_MAX_VEL),
      convertToMotor(cmdvel.angular.z, ANGULAR_Z_MAX_VEL)
    );
  }
  else {
    stopMotors();
  }
  
  watchdog_timer = millis();
}
ros::Subscriber<geometry_msgs::Twist> vel_sub("cmd_vel", &vel_callback);

// Hazards Enable Callback
void hazards_callback(const mecanumbot::RobotHazardsEnableRequest& req, mecanumbot::RobotHazardsEnableResponse& res) {
  // handle request
  hazards_enabled = req.enable;
  if(!hazards_enabled) {
    stopMotors();
  }
  
  // generate response
  res.success = true;
}
ros::ServiceServer<mecanumbot::RobotHazardsEnableRequest, mecanumbot::RobotHazardsEnableResponse> hazard_srv("robot_hazards_enable", &hazards_callback);

// set multiple pixels
void setPixles(byte start, byte num, uint32_t c) {
  for(byte i=start; i<start+num; i++) strip.setPixelColor(i, c);
  strip.show();
}
void setPixle(byte i, uint32_t c) {
  strip.setPixelColor(i, c);
  strip.show();
}

float readFloat() {
  float value;
  byte* p = (byte*)(void*)&value;
  for(unsigned int i = 0; i < sizeof value; i++) {
    *p++ = I2c.receive();
  }
  return value;
}

void stopMotors() {
  controller.cmd_vel(128, 128, 128);
}

void setup()
{
  // Get baseline CPI utilization
  utils.measureIdleUsage(HEALTH_PERIOD);

  // Start I2C
  I2c.begin();
  I2c.timeOut(5); // ms
  // the lower the timeout, the less CPU we waste when the e-stop is enabled
  
  // Start up the LED strip, turn them all off
  strip.begin();
  strip.show();
  setPixles(0, NUM_LEDS, COLOR_OFF);
  
  // Mecanum Setup
  controller = Mecanum();
  controller.cmd_vel(128, 128, 128);
  
  // ROS Setup
  nh.initNode();
  nh.subscribe(vel_sub);
  nh.advertise(enc_pub);
  nh.advertise(health_pub);
  nh.advertiseService(hazard_srv);
  while(!nh.connected()) nh.spinOnce();
  odom_timer = millis();
  enc_msg.data = (float *)malloc(sizeof(float)*4);
  enc_msg.data_length = 4;
  
  // Start BMP sensor
  if(!bmp.begin()) {
    nh.logerror("Could not find a valid BMP085 sensor, check wiring!");
  }
  
  // ready to go! default color state w/ ROS connected
  nh.loginfo("MecanumController startup complete");
  
  // turn on headlights
  setPixle(2, COLOR_WHITE);
  setPixle(3, COLOR_WHITE);
  setPixle(6, COLOR_WHITE);
  setPixle(7, COLOR_WHITE);
  
  // turn on interior light
  setPixles(0, 2, COLOR_WHITE);
}

void loop()
{
  // auto stop motors if we haven't received a cmd_vel message in a while
  if((millis() - watchdog_timer) > WATCHDOG_PERIOD) {
    stopMotors();
    watchdog_timer = millis();
  }
  
  // send odom
  if((millis() - odom_timer) > ODOM_PERIOD) {
    // grab data from encoders
    controller.getEncoderCounts(enc_msg.data); // returned as x, y, theta
    unsigned long currentTime = millis();
    enc_msg.data[3] = (float)(currentTime - odom_timer) / 1000;
    
    // publish data
    enc_pub.publish(&enc_msg);
    if((currentTime - ODOM_PERIOD) > (odom_timer + ODOM_PERIOD)) {
      odom_timer = currentTime;
    }
    else {
      odom_timer = odom_timer + ODOM_PERIOD;
    }
  }
  
  // health timer
  if((millis() - health_timer) > HEALTH_PERIOD) {
    // microcontroller health
    health_msg.cpu_used = utils.cpuUsage(HEALTH_PERIOD); // percentage
    health_msg.mem_used = utils.memUsage(); // percentage
    
    // power board health
    I2c.read((uint8_t)PWR_ADDRESS, (uint8_t)21);
    int avail = I2c.available();
    health_msg.e_wall = readFloat();
    health_msg.e_batt1 = readFloat();
    health_msg.e_batt2 = readFloat();
    health_msg.e_bus = readFloat();
    health_msg.i_bus = readFloat();
    byte pwr_bit = I2c.receive();
    health_msg.wall_avail = bitRead(pwr_bit, 7);
    health_msg.batt1_avail = bitRead(pwr_bit, 6);
    health_msg.batt2_avail = bitRead(pwr_bit, 5);
    health_msg.wall_active = bitRead(pwr_bit, 4);
    health_msg.batt1_active = bitRead(pwr_bit, 3);
    health_msg.batt2_active = bitRead(pwr_bit, 2);
    health_msg.power_switch = bitRead(pwr_bit, 1);
    health_msg.external_switch = bitRead(pwr_bit, 0);
    
    // update LEDs to reflect wall power state
    if(health_msg.wall_active) {
      setPixle(4, COLOR_BLUE);
      setPixle(5, COLOR_BLUE);
    }
    else {
      setPixle(4, COLOR_OFF);
      setPixle(5, COLOR_OFF);
    }
    
    // temperature and pressure
    health_msg.t_internal = bmp.readTemperature();
    health_msg.p_internal = bmp.readPressure();
    health_msg.altitude = bmp.readAltitude(PRESSURE_SL);
    
    // publish
    health_pub.publish(&health_msg);
    health_timer = millis();
  }
  
  // set motor status LEDs
  byte led_sequence = (millis() % 1000) / 125;
  if(hazards_enabled) {
    if(led_sequence == 0 || led_sequence == 2) {
      setPixles(12, 4, COLOR_GREEN);
    }
    else {
      setPixles(12, 4, COLOR_OFF);
    }
  }
  else {
    if(led_sequence == 0 || led_sequence == 1 || led_sequence == 2 || led_sequence == 3) {
      setPixles(12, 4, COLOR_RED);
    }
    else {
      setPixles(12, 4, COLOR_OFF);
    }
  }
  
  // send / receive ROS messages
  nh.spinOnce();
  // ros likes us to wait at least 1ms between loops - this is accounted for in utils.cpuIdle() below
  
  // keep track of an idle CPU
  utils.cpuIdle(); // sleeps 1ms
}

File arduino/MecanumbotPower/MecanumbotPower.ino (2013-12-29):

/*
  MecanumbotPower.ino - Controls power input for the Mecanumbot.
  Created by Josh Villbrandt (http://javconcepts.com/).
  Created in October 2012. Last updated December 2013.
  Released into the public domain.
*/

// Set up I2C
#include <Wire.h>
#include "I2C_Anything.h"

#define DEBUG false
#define PC_STARTUP true
#define REF_5V 4.973 // V
#define ADC_COUNTS 1023.0 // counts
#define ADC_V_MULT ((REF_5V / ADC_COUNTS) / 0.24) // counts to V
#define ADC_I_MULT ((REF_5V / ADC_COUNTS) * (1000.0 / (0.002 * 82500))) // counts to A
#define MIN_VOLT 10.5 // V
#define TURN_OFF_DEBOUNCE 1000 // ms
#define LED_RATE 100 // ms
#define LED_DUTY 65 // ms
const byte MY_ADDRESS = 42;

// Define I/O pins
#define EXT_SW 4
#define EXT_PC 8
byte ledPins[] = {10, 9, 11}; //wall, batt1, batt2
byte fetPins[] = {7, 6, 5}; //wall, batt1, batt2
byte voltagePins[] = {A2, A0, A1, A3, A7}; //wall, batt1, batt2, VIN, PWRSW
byte currentPins[] = {A6};

// State variables
float voltageReadings[] = {0.0, 0.0, 0.0, 0.0, 0.0};
float currentReadings[] = {0.0};
boolean availableSource[] = {true, false, false};
boolean activeSource[] = {true, false, false};
long loopStart = 0;
long loopEnd = 0;
boolean startup = true;
boolean pwrswState = false;
boolean lastPwrswState = false;
long pwrswDebounceTime = 0;
boolean stayPowered = true;

void setup() {
  if(DEBUG) Serial.begin(57600);
  
  // Start I2C
  Wire.begin(MY_ADDRESS);
  Wire.onRequest(telemetryCallback);
  
  // set external interface pins
  pinMode(EXT_SW, INPUT);
  pinMode(EXT_PC, OUTPUT);
  
  // set fet outputs
  for(int i = 0 ; i < 3; i++) {
    pinMode(fetPins[i], OUTPUT);
  }
}

void loop() {
  if(DEBUG) loopStart = micros();
  
  // voltage inputs
  for(int i = 0; i < 5; i++) {
    int sensorValue = analogRead(voltagePins[i]);
    voltageReadings[i] = sensorValue * ADC_V_MULT;
    
    // power source calcs
    if(i <= 2) {
      availableSource[i] = (voltageReadings[i] >= MIN_VOLT);
    }
  }
  
  // current inputs
  for(int i = 0; i < 1; i++) {
    int sensorValue = analogRead(currentPins[i]);
    currentReadings[i] = sensorValue * ADC_I_MULT;
  }
  
  // choose active source
  for(int i = 0 ; i < 3; i++) activeSource[i] = false;
  if(availableSource[0]) activeSource[0] = true; // prefer the wall outlet
  else {
    int voltageMin = 99;
    int indexMin = -1;
    for(int i = 1 ; i < 3; i++) {
      if(availableSource[i] && voltageReadings[i] < voltageMin) {
        voltageMin = voltageReadings[i];
        indexMin = i;
      }
    }
    if(indexMin >= 0) activeSource[indexMin] = true;
    else stayPowered = false; // forcing a clean shutdown, otherwise the uC jitters
  }
  // TODO: this should really have a persistance value and not change source right away (when multiple are present)
  
  // set active source
  for(int i = 0 ; i < 3; i++) {
    // control MOSFET
    if(activeSource[i] && (stayPowered || pwrswState)) digitalWrite(fetPins[i], HIGH);
    else digitalWrite(fetPins[i], LOW);
    
    // set LED
    if(!stayPowered) analogWrite(ledPins[i], 0); // so we know the switch is listening
    else if(activeSource[i] && (stayPowered || pwrswState)) {
      // fancy active indication
      if(millis() % LED_RATE < LED_DUTY) analogWrite(ledPins[i], 255);
      else analogWrite(ledPins[i], 0);
    }
    else if(availableSource[i]) analogWrite(ledPins[i], 127);
    else analogWrite(ledPins[i], 1);
  }
  
  // external PC control
  if(startup && millis() > 3000 && millis() < 4000) digitalWrite(EXT_PC, HIGH);
  else digitalWrite(EXT_PC, LOW);
  if(millis() > 4000) startup = false;
  
  // turn off board
  pwrswState = (!startup && voltageReadings[4] < 5.0); // voltageReadings[4] is not calibrated correctly
  if(pwrswState != lastPwrswState) pwrswDebounceTime = millis();
  if(pwrswState && (millis() - pwrswDebounceTime) > TURN_OFF_DEBOUNCE) stayPowered = false;
  lastPwrswState = pwrswState;
  
  // Debug
  if(DEBUG) {
    loopEnd = micros() - loopStart;
    
    Serial.println("MecanumPower Debug");
    
    Serial.print("e_wall:  \t");
    Serial.print(voltageReadings[0]);
    Serial.println(" V");
    
    Serial.print("e_batt1: \t");
    Serial.print(voltageReadings[1]);
    Serial.println(" V");
    
    Serial.print("e_batt2: \t");
    Serial.print(voltageReadings[2]);
    Serial.println(" V");
    
    Serial.print("e_bus:   \t");
    Serial.print(voltageReadings[3]);
    Serial.println(" V");
    
    Serial.print("i_bus:   \t");
    Serial.print(currentReadings[0], 4);
    Serial.println(" A");
    
    Serial.print("pwr_sw:  \t");
    Serial.println(pwrswState);
    
    Serial.print("ext_sw:  \t");
    Serial.println(digitalRead(EXT_SW));
    
    Serial.print("loop tm: \t");
    Serial.print(loopEnd);
    Serial.println(" us");
    
    delay(500);
    Serial.println();
  }
}

void telemetryCallback()
{
  // build power bit (wall_avail, batt1_avail, batt2_avail, wall_active, batt1_active, batt2_active, power_switch, external_switch)
  byte pwr_bit;
  bitWrite(pwr_bit, 7, availableSource[0]);
  bitWrite(pwr_bit, 6, availableSource[1]);
  bitWrite(pwr_bit, 5, availableSource[2]);
  bitWrite(pwr_bit, 4, activeSource[0]);
  bitWrite(pwr_bit, 3, activeSource[1]);
  bitWrite(pwr_bit, 2, activeSource[2]);
  bitWrite(pwr_bit, 1, pwrswState);
  bitWrite(pwr_bit, 0, digitalRead(EXT_SW));

  byte buffer[21];
  unsigned int buffer_position;
  buffer_position = addToBuffer(buffer, buffer_position, voltageReadings[0]); // e_wall
  buffer_position = addToBuffer(buffer, buffer_position, voltageReadings[1]); // e_batt1
  buffer_position = addToBuffer(buffer, buffer_position, voltageReadings[2]); // e_batt2
  buffer_position = addToBuffer(buffer, buffer_position, voltageReadings[3]); // e_bus
  buffer_position = addToBuffer(buffer, buffer_position, currentReadings[0]); // i_bus
  buffer_position = addToBuffer(buffer, buffer_position, pwr_bit);
  
  Wire.write(buffer, 21);
}

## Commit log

2013-03-18 adding odometry_publisher
2013-03-18 adding the rest of the package - most files still need to be updated for groovy
    [Mecanumbot Velocity Calibration.xlsx, mecanumbot.urdf]
2013-03-19 fixed the kinect frame name in the urdf and restarted the rviz file w/ new rviz
2013-03-30 more work on launch files (laser works now) and started some setup scripts
    [mecanumbot.urdf]
2013-04-06 setting up for new arduino board
2013-04-14 Update RobotHealth.msg
    moving temp and pressure to bottom and adding units for pressure
2013-12-08 info for laser and udev rules
2013-12-08 instructions for uploading arduino code
2013-12-08 better todo list, arduino info, upower bug info
2013-12-09 removed sensor_msgs references
2013-12-10 cleaned up commented out code, better color filtering
2013-12-15 creating an average filter
2013-12-16 average filter works!
2013-12-16 target_follower uses filter now
2013-12-16 filtering from odom frame now
2013-12-19 adding arduino files
2013-12-25 ball tracker now uses HSV space for color filtering
2013-12-25 power board telemetry
2013-12-26 added notes for new LED message
2013-12-27 a couple more tweaks on what the light action syntax might be
2013-12-27 added todo for mecanumbot power shutdown
2013-12-29 better arduino cpu reporting
2013-12-29 adding power arduino code
2013-12-29 battery LEDs turn off when off button is pressed
2013-12-29 adding pressure and temperature lib
2013-12-29 power board finally gives i2c telemetry!!!!
2013-12-29 successfully pulling telemetry from the power board into ros through the controller arduino
2013-12-29 moved the BMP library to I2C instead of Wire
2013-12-29 renamed BMP lib w/ I2C (not Wire) as to not conflict with Lady Ada's normal lib
2013-12-29 changed sea level pressure
2013-12-29 fixed velocity calibration table
2013-12-30 i2c troubleshooting
2013-12-30 i2c oscope pictures
2013-12-31 lower motor deadzone
2016-01-15 Add motor hazard enable service
2016-01-15 Update LED colors
2016-01-16 Add successful hector slam maps
    [mecanumbot.urdf]
2016-02-12 Add full model robot description
    [base_laser.STL, base_link.STL, bl_wheel_link.STL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]
2016-02-12 Use new description by default
    [mecanumbot-simple.urdf]
